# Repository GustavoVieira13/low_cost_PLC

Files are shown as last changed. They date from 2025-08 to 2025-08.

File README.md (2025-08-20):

# low_cost_PLC
Low Cost PLC Prototype developed in my master thesis. This prototype consists on an add on PCB to the Raspberry Pi computer board capable of controlling a FischerTechnik simulation plant with software compliant to IEC 61131-3 and IEC 61499. Thesis grade: 19/20.
https://bibliotecadigital.ipb.pt/bitstream/10198/22828/1/Vieira_Gustavo.pdf&ved=2ahUKEwj17py7npqPAxUhQ_EDHYJfIWkQFnoECB0QAQ&usg=AOvVaw03RJ8QUEFN0XCKA-qMjsA1

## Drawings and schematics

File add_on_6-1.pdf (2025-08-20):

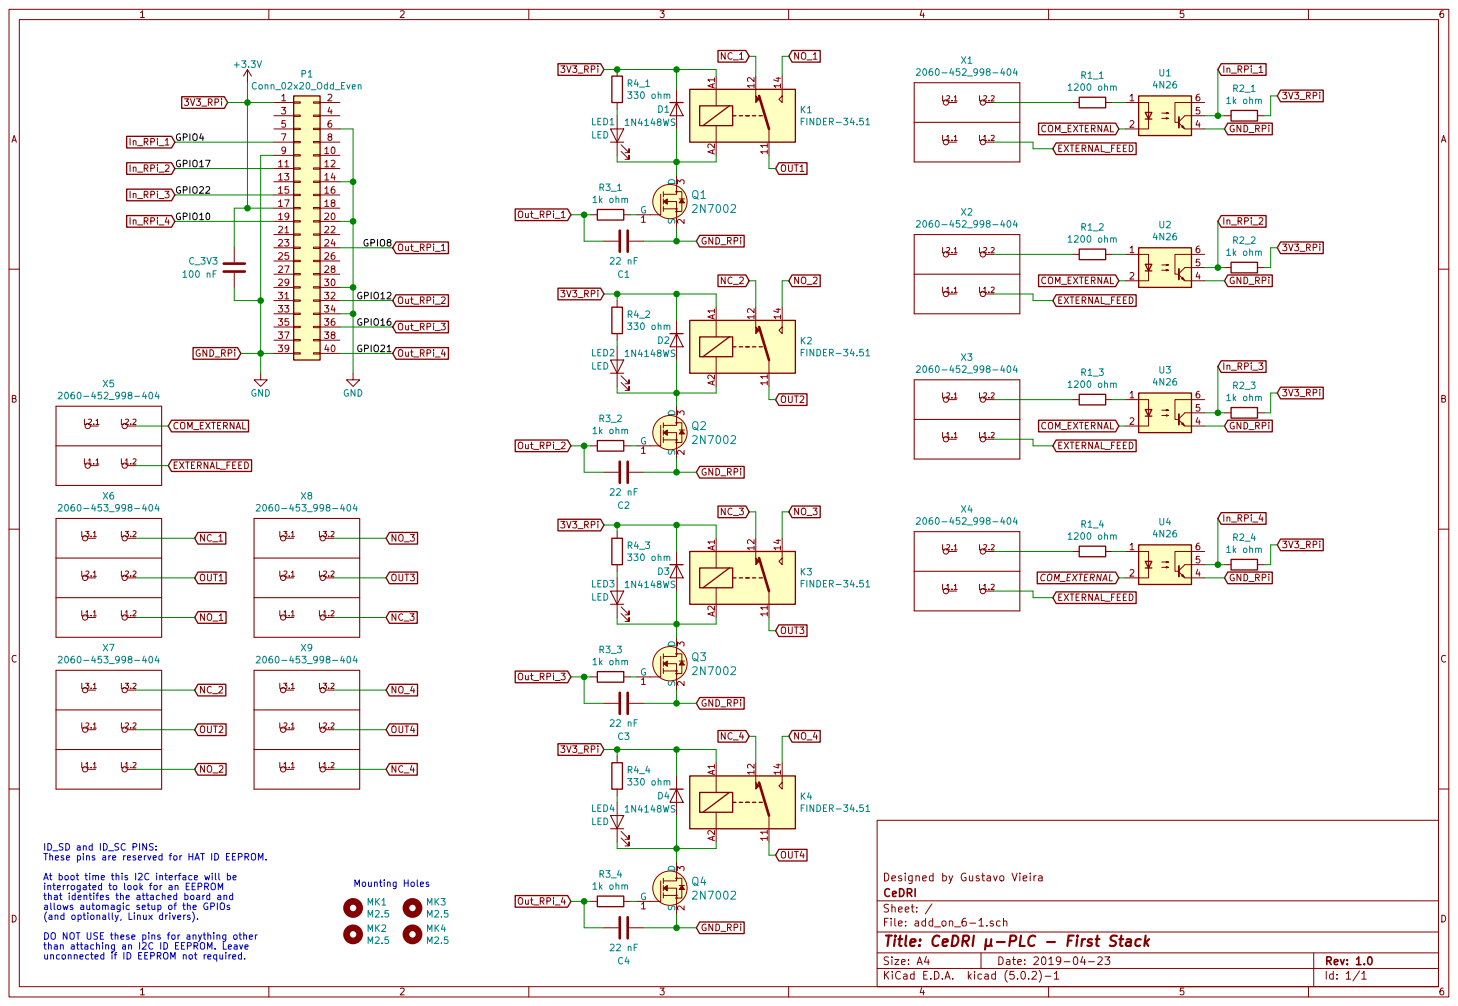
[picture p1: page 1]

ID_SD and ID_SC PINS: These pins are reserved for HAT ID EEPROM. At boot time this I2C interface will be

interrogated to look for an EEPROM
that identifes the attached board and
allows automagic setup of the GPIOs
(and optionally, Linux drivers).
DO NOT USE these pins for anything other
than attaching an I2C ID EEPROM. Leave

Id: 1/1 Title: CeDRI -PLC - First Stack

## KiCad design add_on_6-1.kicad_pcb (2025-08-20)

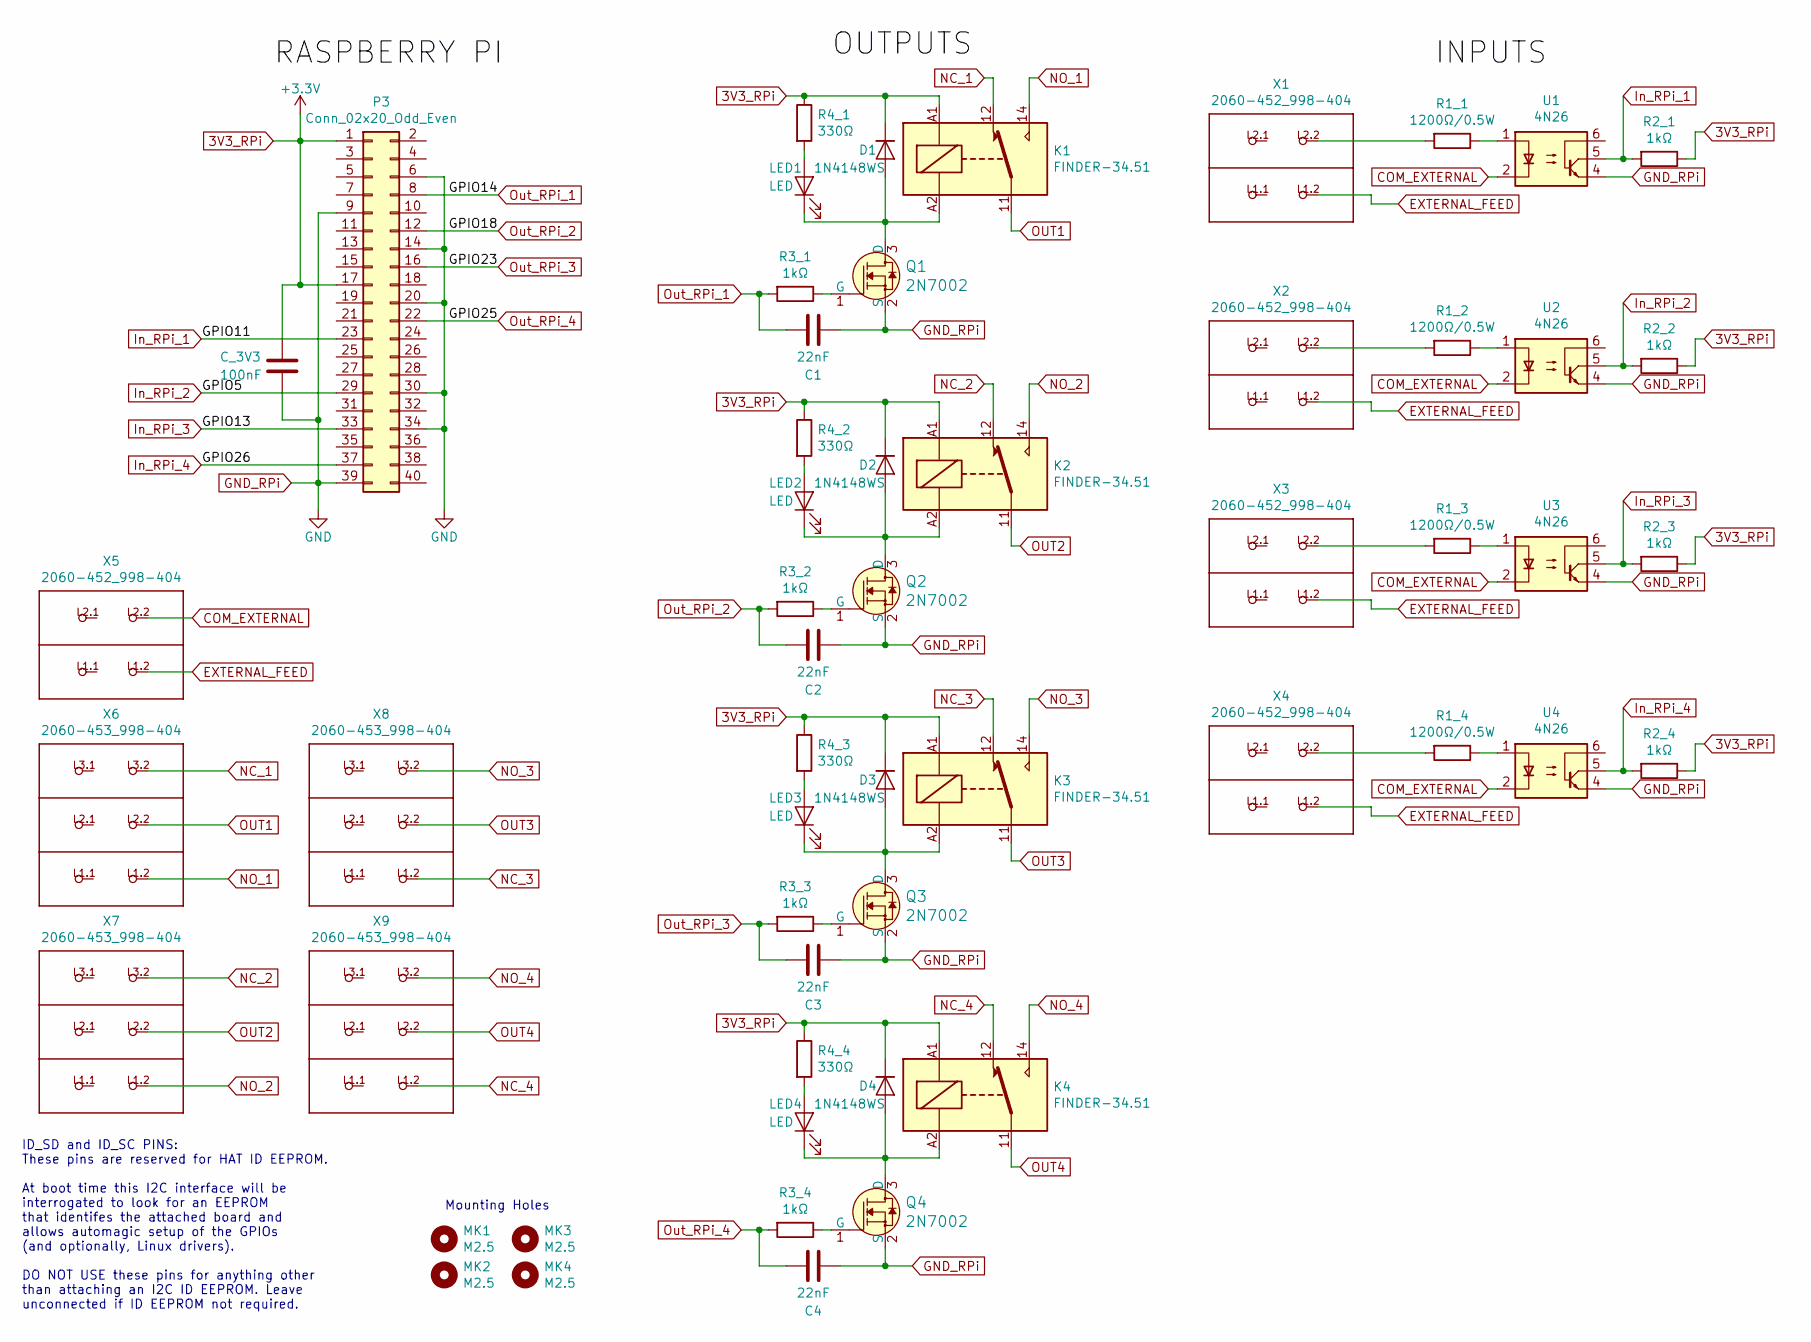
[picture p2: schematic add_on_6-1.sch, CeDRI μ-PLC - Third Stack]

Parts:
C1, C2, C3, C4: 22nF; C_0805_2012Metric
C_3V3: 100nF; C_0805_2012Metric
D1, D2, D3, D4: 1N4148WS; D_SOD-323
K1, K2, K3, K4: FINDER-34.51; Relay_SPDT_Finder_34.51_Vertical
LED1, LED2, LED3, LED4: LED; LED_0805_2012Metric
MK1, MK2, MK3, MK4: M2.5; MountingHole_2.7mm_M2.5
P3: Conn_02x20_Odd_Even; PinSocket_2x20_P2.54mm_Vertical
Q1, Q2, Q3, Q4: 2N7002; SOT-23-3; MPN 2N7002; Digi-Key_PN 2N7002NCT-ND
R1_1, R1_2, R1_3, R1_4: 1200Ω/0.5W; R_0805_2012Metric
R2_1, R2_2, R2_3, R2_4, R3_1, R3_2, R3_3, R3_4: 1kΩ; R_0805_2012Metric
R4_1, R4_2, R4_3, R4_4: 330Ω; R_0805_2012Metric
U1, U2, U3, U4: 4N26; DIP-6_W7.62mm
X1, X2, X3, X4, X5: 2060-452_998-404; P-2060-452%2f998-404
X6, X7, X8, X9: 2060-453_998-404; P-2060-453%2f998-404

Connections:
3V3_RPi: C_3V3.1, D1.1 (K), D2.1 (K), D3.1 (K), D4.1 (K), K1.A1, K2.A1, K3.A1, K4.A1, P3.1, P3.17, R2_1.1, R2_2.1, R2_3.1, R2_4.1, R4_1.1, R4_2.1, R4_3.1, R4_4.1
COM_EXTERNAL: U1.2, U2.2, U3.2, U4.2, X5.L2.2 (P2.2)
EXTERNAL_FEED: X1.L1.2 (P1.2), X2.L1.2 (P1.2), X3.L1.2 (P1.2), X4.L1.2 (P1.2), X5.L1.2 (P1.2)
GND_RPi: C1.1, C2.1, C3.1, C4.1, C_3V3.2, P3.6, P3.9, P3.14, P3.20, P3.30, P3.34, P3.39, Q1.2 (S), Q2.2 (S), Q3.2 (S), Q4.2 (S), U1.4, U2.4, U3.4, U4.4
In_RPi_1: P3.23, R2_1.2, U1.5
In_RPi_2: P3.29, R2_2.2, U2.5
In_RPi_3: P3.33, R2_3.2, U3.5
In_RPi_4: P3.37, R2_4.2, U4.5
NC_1: K1.12, X6.L3.2 (P3.2)
NC_2: K2.12, X7.L3.2 (P3.2)
NC_3: K3.12, X8.L1.2 (P1.2)
NC_4: K4.12, X9.L1.2 (P1.2)
NO_1: K1.14, X6.L1.2 (P1.2)
NO_2: K2.14, X7.L1.2 (P1.2)
NO_3: K3.14, X8.L3.2 (P3.2)
NO_4: K4.14, X9.L3.2 (P3.2)
unnamed: D1.2 (A), K1.A2, LED1.1 (K), Q1.3 (D)
unnamed: D2.2 (A), K2.A2, LED2.1 (K), Q2.3 (D)
unnamed: D3.2 (A), K3.A2, LED3.1 (K), Q3.3 (D)
unnamed: D4.2 (A), K4.A2, LED4.1 (K), Q4.3 (D)
unnamed: LED1.2 (A), R4_1.2
unnamed: LED2.2 (A), R4_2.2
unnamed: LED3.2 (A), R4_3.2
unnamed: LED4.2 (A), R4_4.2
unnamed: Q1.1 (G), R3_1.1
unnamed: Q2.1 (G), R3_2.1
unnamed: Q3.1 (G), R3_3.1
unnamed: Q4.1 (G), R3_4.1
unnamed: R1_1.1, U1.1
unnamed: R1_1.2, X1.L2.2 (P2.2)
unnamed: R1_2.1, U2.1
unnamed: R1_2.2, X2.L2.2 (P2.2)
unnamed: R1_3.1, U3.1
unnamed: R1_3.2, X3.L2.2 (P2.2)
unnamed: R1_4.1, U4.1
unnamed: R1_4.2, X4.L2.2 (P2.2)
OUT1: K1.11, X6.L2.2 (P2.2)
OUT2: K2.11, X7.L2.2 (P2.2)
OUT3: K3.11, X8.L2.2 (P2.2)
OUT4: K4.11, X9.L2.2 (P2.2)
Out_RPi_1: C1.2, P3.8, R3_1.2
Out_RPi_2: C2.2, P3.12, R3_2.2
Out_RPi_3: C3.2, P3.16, R3_3.2
Out_RPi_4: C4.2, P3.22, R3_4.2

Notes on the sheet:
ID_SD and ID_SC PINS: These pins are reserved for HAT ID EEPROM. At boot time this I2C interface will be interrogated to look for an EEPROM that identifes the attached board and allows automagic setup of the GPIOs (and optionally, Linux drivers). DO NOT USE these pins for anything other than attach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
Mounting Holes

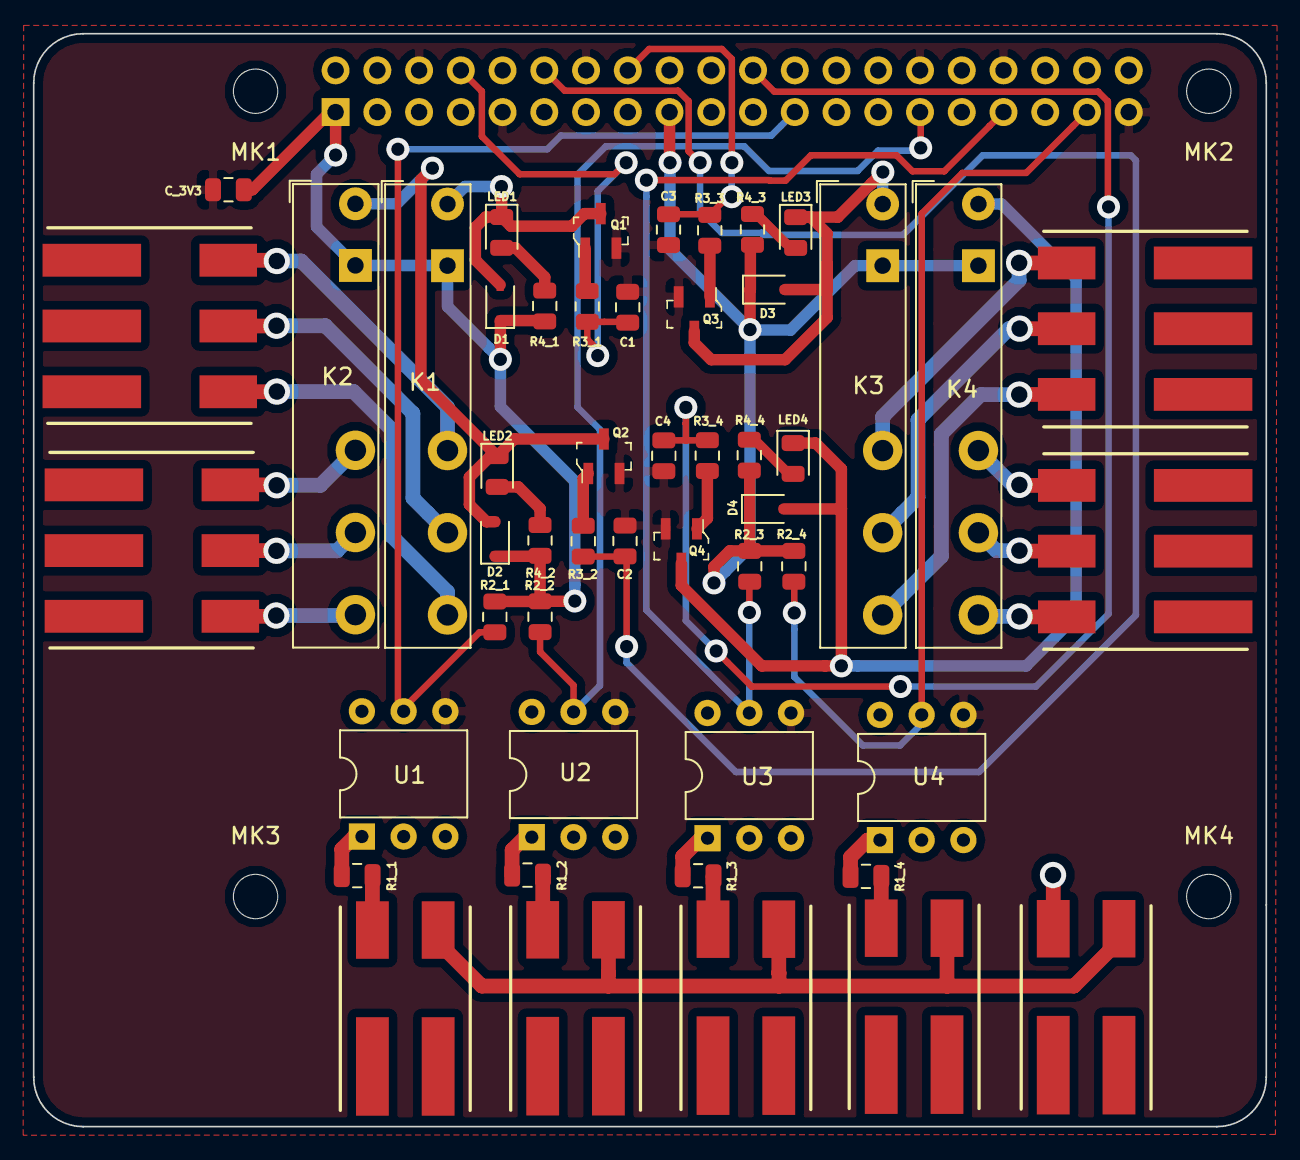
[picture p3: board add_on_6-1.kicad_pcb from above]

Board: 2 copper layers, 75.0 x 66.5 mm, 55 parts (1 on the bottom side), 44 nets.
